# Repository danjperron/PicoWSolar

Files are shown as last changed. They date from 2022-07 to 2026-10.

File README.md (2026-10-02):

# PicoWSolar
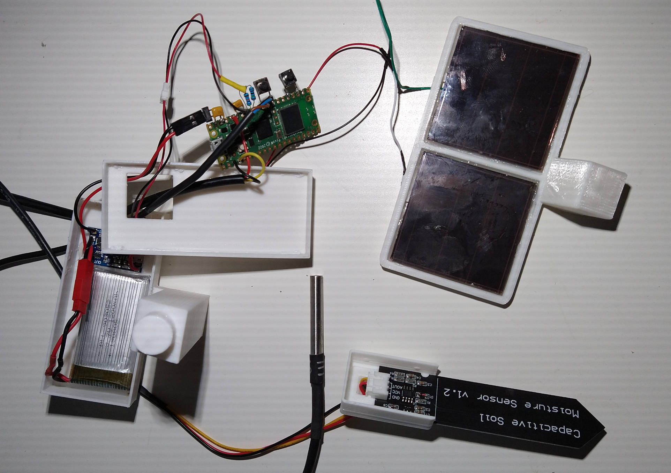
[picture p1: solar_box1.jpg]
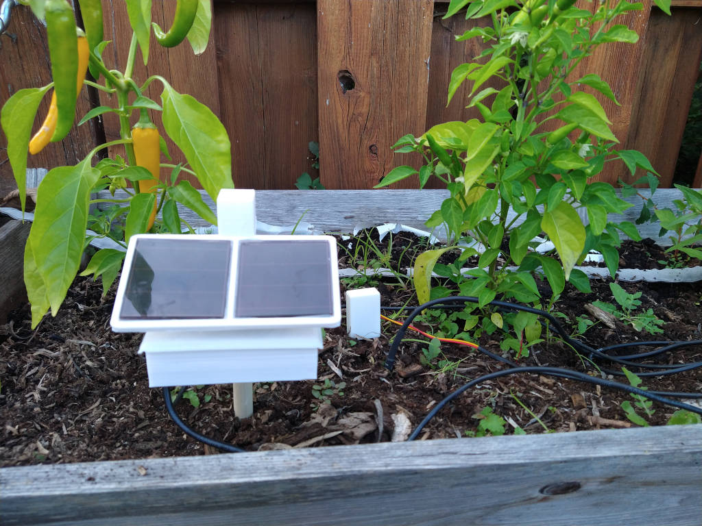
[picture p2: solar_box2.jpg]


*** october 2026 I added a second picow with nodered valve control.<br><br>
This is a PicoW with a 3.7V lipo battery charged by two old solar cells (2.6V max open and ~25ma short).

I modified the TP4056 charger by replacing the TP4056 I.C. with a low drop diode (~0.2V) on low current.
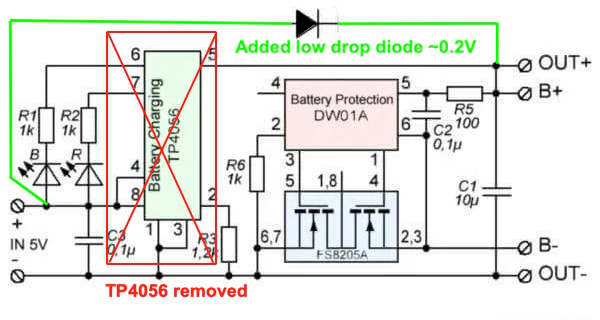
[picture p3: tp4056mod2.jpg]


N.B. you don't need to modiify the TP4056. I did that because my solar cells were not powerfull enough but new ones I bought were good enough.

Data are sent by MQTT to a mosquitto server and after it goes to light sleep. The running cycle depends of the battery Voltage  from 1 to 5 minutes. Right now a minute cycle will discharge the battery even in full sun. This is a good way to be sure that it will never overcharged the battery.

The system publish 5 topics which are,
- Vsys. The Lipo battery Voltage.
- Vsolar. The solar cell voltage.
- tempCPU. The internal temperature of the cpu.
- DS18B20. The ds18B20 temperature. Could multiple sensor on same pin.
- Vmoist. The Voltage of the moist sensor two possible (Vmoist_0 and Vmoist_1).
- bmeT,bmeP,bmeH.  bme280 temperature, pression and humidity.

The bme280 sensor was added. It is necessary to install the library from https://github.com/SebastianRoll/mpy_bme280_esp8266.
The adafruit bme280 i2c address is 0x77.

On the new version it is possible to enable the watchdog. On preliminary test you should disable it. Because of the watchdog the
lightsleep can't be more than 8.3 seconds, this is why we have wd_lightsleep() which split the lightsleep in 5 seconds.

Before I do the nodered page I just made simple scripts to check if everything is ok
- On the MQTT broker I ran a script all the times to record all topics from the PicoW with time.<br>
<quote>mosquitto_sub -h 10.11.12.192 -v -t "PicoW/#" | xargs -d$'\n' -L1 bash -c 'date "+%Y-%m-%d %T.%3N $0"'  >>solar.txt</quote>
- I create a python script that open an excel workbook and transfer the data and automatically open excel with the chart.
- To get the latest 2 days information I just type  "~/getsolar" and the chart displayed.

Description of the file,
- mqtt_ds18B20.py   Main python script store in the pico. You need to change it to main.py when every is working.
- <strike>secrets.py.       Dictionnary which old all info about the wifi and the topics namea. Needs to be store in pico.</strike>
- extractxl.py      Python script to feed data into the excel workbook. (Python script on my computer)
- getsolar          Bash shell to transfer the latest data and display the chart on excel. Small change needs for window .bat file.
- picowsolar.fzz    This is Fritzing schema
- picowsolar_schema.jpg  Schema
- STL folder contains all stl of the 3D case.  Made with tinkercad  <a href="https://www.tinkercad.com/things/b1r0aMqMbmD-picowsolar">picow_solar</a>
- flows.json         NodeRed flow export . Include Voltage, Temperature and moist gauge plus daily and weekly chart.
                    N.B. you need the dashboard module for nodered.<br>
- flows2.json        NodeRed flow export version with bme sensor.<br>
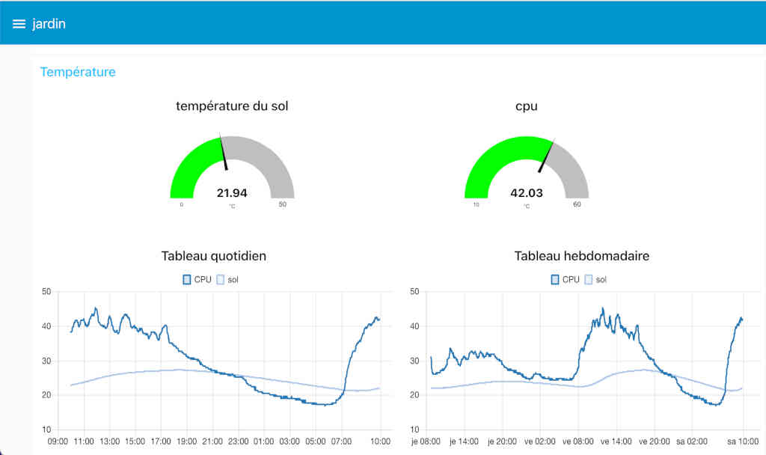
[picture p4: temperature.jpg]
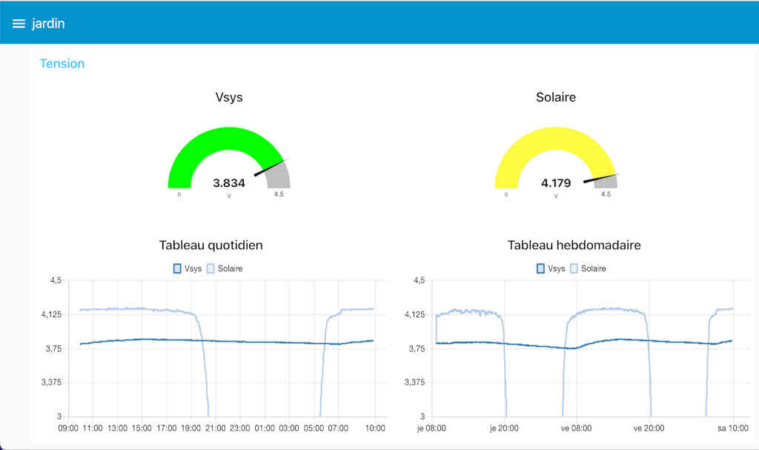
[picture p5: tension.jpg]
&nbsp;&nbsp;&nbsp;<br><br><br>
Before you change the file mqtt_ds18B20.py to main.py  please verify if everything is ok. First disable the watchdog  and change ds18B20 sensors id.

N.B. Most recent 2023 firmware don't have the lightsleep working very well. Please use the uf2 incuded in this github

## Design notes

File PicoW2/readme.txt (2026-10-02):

flow.json is the new nodered flow with the valve activation

This is the content of the PicoW 
When everything is ok rename PicoW2Solar.py to main.py
This way it will start automatically.
If you need to stop  reset and press the stop button.
This will break main.py and you will be able to use thonny. 

├── lib
│   ├── bme280.py
│   ├── umqtt
│   │   └── simple.py
│   └── uping.py
└── PicoW2Solar.py

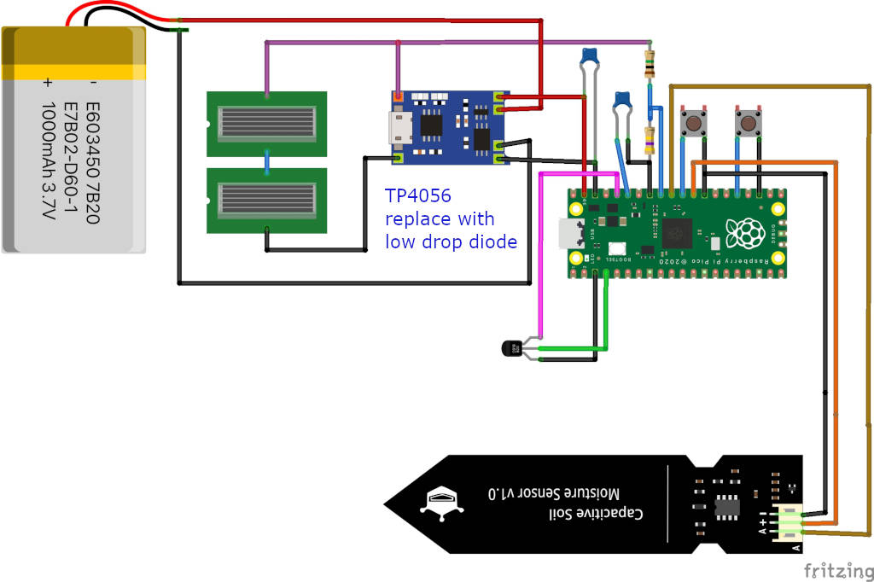
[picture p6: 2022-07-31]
picowsolar_schema.jpg

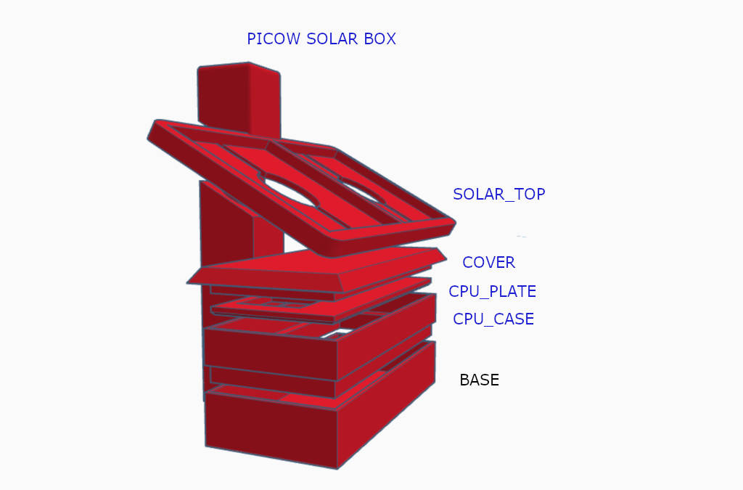
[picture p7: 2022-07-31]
PicoWBox3D.jpg

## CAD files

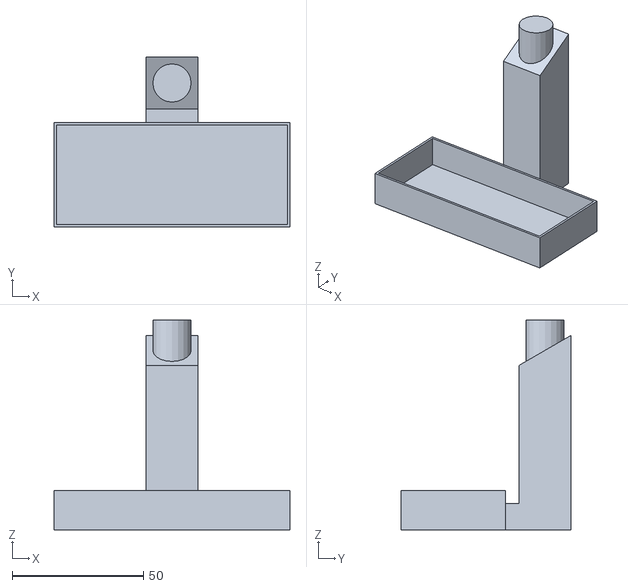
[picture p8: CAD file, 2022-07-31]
stl/picow_solar_base.stl
90.0 x 65.0 x 80.0

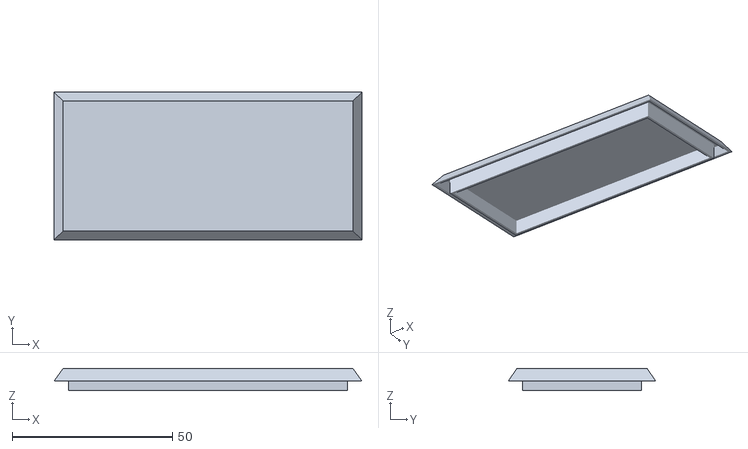
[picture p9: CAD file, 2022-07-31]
stl/picow_solar_cover.stl
96.0 x 46.0 x 7.00

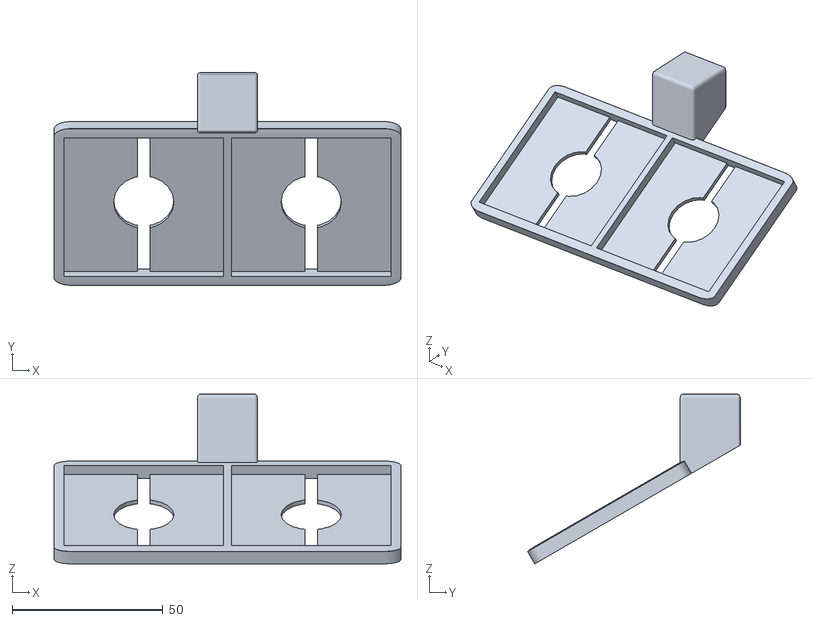
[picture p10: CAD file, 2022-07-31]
stl/picow_solar_top.stl
115.0 x 70.5 x 56.3

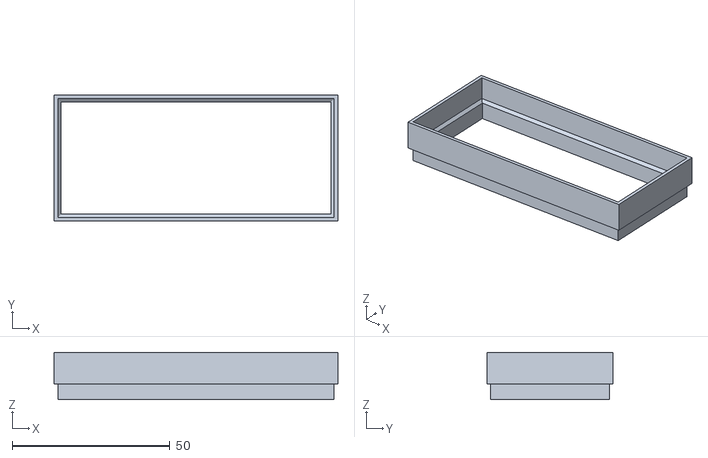
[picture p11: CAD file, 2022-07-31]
stl/picow_solar_cpu_case.stl
90.0 x 40.0 x 15.0

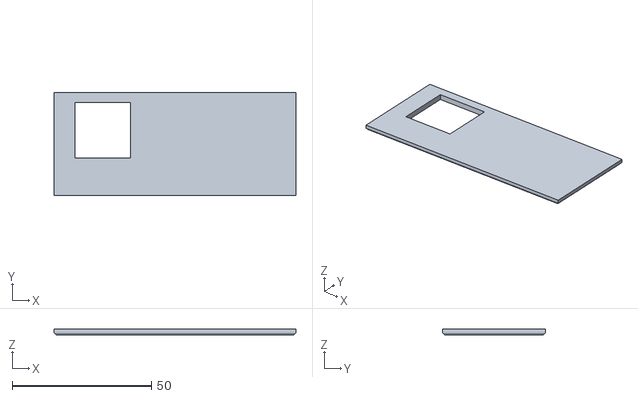
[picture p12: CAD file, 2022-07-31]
stl/picow_solar_cpu_plate.stl
87.0 x 37.0 x 2.00

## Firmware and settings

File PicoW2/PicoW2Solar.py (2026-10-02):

import machine
import rp2
import network
import ubinascii
import time
import sys
from onewire import OneWire
from ds18x20 import DS18X20
from umqtt.simple import MQTTClient
import bme280       #importing BME280 library

#debug
uart = machine.UART(0,baudrate=115200,tx=machine.Pin(0),rx=machine.Pin(1))

uart.write("Start main()\r\n")



#network definition
wifi_essid = "your essid"
wifi_password = "your password"


# define IP,mask and gateway if IP is static
UseStaticIP = True
IP = "10.11.12.22"
IP_mask = "255.255.255.0"
IP_gateway = "10.11.12.253"
IP_DNS = "8.8.8.8"
IP_MQTT_BROKER = "10.11.12.135"

UnitID = "PicoW2"

#do we want to use watchdog to reset in case
WatchDog_Enable = True

#sensors definition
#DS18B20 sensors on the same Pin
#more than one sensor could be defined
#if DS18B20Sensors is None then a scan will be done
DS18B20Pin = 2
DS18B20Sensors  = [ (0x28,0xff,0x2d,0x7b,0xc1,0x17,0x1,0x44) ]
#DS18B20Sensors=None


#ADC Sensors
#Solar sensor needs
ADC_VoltConversion= 3.3 / (65535)

ADC1_Enable=True
ADC1_PinPower=None
ADC1_Pin=27
ADC1_Topic="Vsolar"
ADC1_CorrectionFactor= 1.08
ADC1_Factor= ADC_VoltConversion * ADC1_CorrectionFactor * 3.12765957447  #470k & 1M   (470K + 1M) / 470K



#moist sensors needs power Pins and ADC 
# two possible moist sensor ADC(0) and ADC(2)
ADC0_Enable=True
ADC0_PinPower=22
ADC0_Pin=26
ADC0_Topic="Vmoist_0"
ADC0_CorrectionFactor= 1.0
ADC0_Factor= ADC_VoltConversion * ADC0_CorrectionFactor



ADC2_Enable=False
ADC2_PinPower=None
ADC2_Pin=28
ADC2_Topic="Vmoist_1"
ADC2_CorrectionFactor= 1.0
ADC2_Factor= ADC_VoltConversion * ADC2_CorrectionFactor


#bme280 sensors
bme_Enable = False
bme_PinSDA=4
bme_PinSCL=5
bme_i2c_address = 0x77
bme_temperature_topic = "bmeT"
bme_pressure_topic = "bmeP"
bme_humidity_topic = "bmeH"

# stop switch  (Press to quit on reset if file is main.py)
switchPin = 19
#ok let's set the Pins
sw = machine.Pin(switchPin,machine.Pin.IN,machine.Pin.PULL_UP)

time.sleep_ms(10)

#On boot do we want to stop main() if yes exit
if  sw.value() == 0:
    sys.exit()


#### WATCH DOG 
# set maximum wachtdog 8.3s  ( 2**24 -1)/2
wdt = machine.WDT(timeout=8300000)

# define lightsleep with watch dog limits
# because we implemented wachtdog we need to
# maximize the light sleep to be lower than 8 second
# the watch dog is 24 bits at 1us clock  by a count of 2
# then the maximum is (2 power 24 -1)/2 which is ~8.3 sec
#  we will use 5 seconds step
def wd_lightsleep(value):
    uart.write("lightsleep({})\r\n".format(value))
    time.sleep_ms(200)
    if WatchDog_Enable:
        while value >0:
            if value >= 5000:
                machine.lightsleep(5000)
                value = value - 5000
            else:
                machine.lightsleep(value)
                value=0
            wdt.feed()
    else:
         machine.lightsleep(value)
    wdt.feed()
    time.sleep_ms(200)     
    uart.write("Wake from lightsleep()\r\n")


#ok let's set the Pins
#i2c
# in bme280 i2c address was 0x76 put adafruit need to be 0x77

if bme_Enable:
    i2c=machine.I2C(0,sda=machine.Pin(bme_PinSDA), scl=machine.Pin(bme_PinSCL), freq=100000)    #initializing the I2C method 
    bme = bme280.BME280(i2c=i2c,address=bme_i2c_address)

#Led
led = machine.Pin('LED', machine.Pin.OUT)

#analog
#first set Pin input no pull first
#moist sensors VCC is on a Pin. we need to set pi High to activate sensor 
# two possible  moist sensor ADC(0) and ADC(2)
#pin object definitioin
ADC0=None
ADC1=None
ADC2=None
ADC0_PWR=None
ADC1_PWR=None
ADC2_PWR=None


if ADC0_Enable:
    #set PIN to INPUT first no pull
    ADC0_IN = machine.Pin(ADC0_Pin,machine.Pin.IN)
    ADC0= machine.ADC(ADC0_Pin -26)

if ADC1_Enable:
    ADC1_IN = machine.Pin(ADC1_Pin,machine.Pin.IN)
    ADC1= machine.ADC(ADC1_Pin -26)

if ADC2_Enable:
    ADC2_IN = machine.Pin(ADC2_Pin,machine.Pin.IN)
    ADC2= machine.ADC(ADC2_Pin -26)


def PowerAnalogPin(flag):
    if ADC0_Enable:
        if not (ADC0_PinPower==None):
            if flag:
                ADC0_PWR= machine.Pin(ADC0_PinPower,machine.Pin.OUT)
                ADC0_PWR.value(1)
            else:
                ADC0_PWR= machine.Pin(ADC0_PinPower,machine.Pin.IN)

    if ADC1_Enable:
        if not (ADC1_PinPower==None):
            if flag:
                ADC1_PWR= machine.Pin(ADC1_PinPower,machine.Pin.OUT)
                ADC1_PWR.value(1)
            else:
                ADC1_PWR= machine.Pin(ADC1_PinPower,machine.Pin.IN)
    if ADC2_Enable:
        if not (ADC2_PinPower==None):
            if flag:
                ADC2_PWR= machine.Pin(ADC2_PinPower,machine.Pin.OUT)
                ADC2_PWR.value(1)
            else:
                ADC2_PWR= machine.Pin(ADC2_PinPower,machine.Pin.IN)

            

#one wire
ds = DS18X20(OneWire(machine.Pin(DS18B20Pin)))

if DS18B20Sensors==None:
    DS18B20Sensors=ds.scan()


#cpu temperature declaration
cpu_temp = machine.ADC(machine.ADC.CORE_TEMP)
conversion_factor = 3.3 / (65535)

def readCpuTemperature():
  reading = cpu_temp.read_u16() * conversion_factor
  return 27 - (reading - 0.706)/0.001721
    

def setPad(gpio, value):
    machine.mem32[0x4001c000 | (4+ (4 * gpio))] = value
    
def getPad(gpio):
    return machine.mem32[0x4001c000 | (4+ (4 * gpio))]


def readVsys():
    oldpad = getPad(29)
    setPad(29,128)  #no pulls, no output, no input
    adc_Vsys = machine.ADC(3)
    Vsys = adc_Vsys.read_u16() * 3.0 * conversion_factor
    setPad(29,oldpad)
    return Vsys


def readAnalog(Analog, factor):
    if Analog == None:
        return None
    return Analog.read_u16() * factor

def readBme():
    try:
        t, p, h = bme.read_compensated_data()
        t, p, h = bme.read_compensated_data()
        return (t/100.0 , p/25600.0, h/1024.0)
    except OSError as e:
        pass
    return None    

#network declaration
# Set country to avoid possible errors / https://randomnerdtutorials.com/micropython-mqtt-esp32-esp8266/
rp2.country('CA')
wlan=None
client=None

def stopWifi():
    global client
    global wlan
    uart.write("Stop wifi()\r\n")
    if not(client==None):
        uart.write("Disconnect MQTT\r\n")
        client.disconnect()
        client=None
    if not(wlan==None):
        wlan.disconnect()
        wlan.active(False)
        wlan.deinit()
        wlan=None
    time.sleep_ms(100)
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

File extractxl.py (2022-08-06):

import sys
import datetime
import openpyxl

ExcelFile = "/Users/danielperron/Desktop/projet/SOLAR/Solar.xlsx"
solarFile = "/Users/danielperron/Desktop/projet/SOLAR/solar.txt"
#open excel
wb = openpyxl.load_workbook(ExcelFile)

#first vSys

format1 = 'yyyy\\-mm\\-dd'
format2 = 'hh:mm:ss'

now = datetime.datetime.now()


def TransferData(fileName,mask, ws, factor=1.0):
    f = open(fileName)
    count = 1
    while(True):
        l = f.readline()
        if len(l)==0 : break
        if l.find(mask) <0 :
             continue
        pos = l.find(".")
        thestamp = l[:pos].split(" ")
        thedate = [ int(i) for i in thestamp[0].split('-')]
        thetime = [ int(i) for i in thestamp[1].split(':')]
        exceldate = datetime.datetime(thedate[0],thedate[1],thedate[2],0,0)
        exceldatetime = datetime.datetime(thedate[0],thedate[1],thedate[2],thetime[0],thetime[1],thetime[2])
        ndays = (now - exceldatetime).days
        seconds = (now - exceldatetime).seconds
        #print(ndays)
        if ndays > 2:
            continue
#        if ndays > 1:
#           if seconds > (12 * 3600):
#             continue
            
        exceltime = datetime.time(thetime[0],thetime[1],thetime[2])
        pos = l.find('PicoW')
        topicvalue = ' '.join(l[pos:].split()).split(' ')
        value = float(topicvalue[1])

        ws.cell(row=count,column=1).value=exceldate
        ws.cell(row=count,column=1).number_format=format1
        ws.cell(row=count,column=2).value=exceltime
        ws.cell(row=count,column=2).number_format=format2
        ws.cell(row=count,column=3).value=exceldatetime
        ws.cell(row=count,column=3).number_format=format2
        ws.cell(row=count,column=4).value=value * factor
        count=count+1
    #ok now we need to erase everything left
    ws.delete_rows(count,10000)
    

TransferData(solarFile,"Vsys",wb['vSys'])
TransferData(solarFile,"Vsolar",wb['vSolar'])
TransferData(solarFile,"DS18B20_0 ",wb['ds18b20'])
TransferData(solarFile,"tempCPU",wb['cpu'])
TransferData(solarFile,"Vmoist_0",wb['vHydro'])
wb.save(ExcelFile)
wb.close()

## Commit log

2022-07-31 initial git
    [SOLAR.xlsx, picowsolar.fzz]
2022-07-31 add stl files
    [picow_solar_base.stl, picow_solar_cover.stl, picow_solar_cpu_case.stl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]
2022-08-01 Add files via upload
    empty excel
    [SOLAR.xlsx]
2022-08-02 Different cycle versus Lipo Voltage
2022-08-02 split multiple spacing to get correct value
    [extractxl.py]
2022-08-02 correct temperature chart title french
    [SOLAR.xlsx]
2022-08-04 add nodered flow
2022-08-04 add nodered flow export
2022-08-04 fix nodered flow
2022-08-04 fix name of nodered flows
2022-08-07 add bme nodered flow
2023-02-19 fix watchdog time. it's ms and not µs
    [mqtt_ds18B20.py]
2026-10-02 add second Pico + nodered valve
2026-10-02 Update README with details on second PicoW
    Added information about the second PicoW with Node-RED valve control.
2026-10-02 fix flow chart location
